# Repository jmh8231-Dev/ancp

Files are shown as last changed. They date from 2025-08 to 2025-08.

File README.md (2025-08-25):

# ANCP Rocket Motor Test Station (Rev 2.0)

> 고정추진제 로켓 모터(ANCP) 지상시험을 위한 **정밀 계측·점화 제어 스테이션**  
> 고정밀 아날로그 체인(로드셀/압력/열전대), **안전 중심 점화 시퀀스**, **2″ LCD(LVGL9 + SPI DMA)** GUI, PC 텔레메트리 지원

보드 히어로 이미지

---

##  주요 기능

- **안전 중심 점화 플로우**
  - 물리 **IGN 스위치** 감지 → 카운트다운 → 온도/추력 인터록 → 핫와이어 제어
  - 모터/보드/PC 준비 상태 점검(미준비 시 시험 중지)
- **정밀 계측 체인**
  - 로드셀(추력), 챔버 압력, 노즐/내부 온도(열전대), IMU 진동
  - 메인/IGN 배터리 **셀 별 전압** + 메인 배터리 전류(INA219)
- **2″ LCD GUI (LVGL v9)**
  - **SPI DMA** 플러시(논블로킹), SquareLine Studio 기반 화면
  - Idle/Test/Config/Cal 페이지, FPS 확보 위해 라인 버퍼 + DMA 이중버퍼
- **EEPROM 기반 설정/보정**
  - **32B 페이지** 체크섬 저장 포맷(캘리브레이션 오프셋/설정값 무결성 보장)
- **PC/RF 텔레메트리**
  - 헤더·길이·페이로드·체크섬으로 구성된 패킷 전송
- **RTOS 태스킹**
  - sensing / gui / comms / control / logging 분리

---

##  하드웨어 개요

| 항목 | 부품 |
|---|---|
| MCU | **STM32H723VGT6** (H7, 12 MHz TCXO) |
| 정밀 ADC | **ADS1262IPW** (ΔΣ, 24-bit) |
| SPI 절연 | **ADuM4151** (MCU–ADC) |
| 기준전압 | **ADR4525D** |
| Op-Amp | **OPA189**, **MCP6022**, **TLV9351** |
| 전류 센서 | **INA219** (메인 배터리) |
| IMU | **BNO085** (I²C) |
| 온도 센서 | **AS6221** (MOSFET 온도) |
| EEPROM | **AT24C08C** (I²C) |
| 전원 | LM2596S-3.3, **CC6-1212DR-E**(±12 V) → **LT3045**(+5 V) / **LT3094**(−5 V) / **TPS79225**(+2.5 V) / **TPS72325**(−2.5 V) |
| 점화 경로 | **TC427** 게이트 드라이버 + **IRF1404** 파워 MOSFET, 물리 **IGN SW** |
| I/O | 2″ LCD, F1–F4 버튼, 부저, USB-UART(FT232RL), RF 모듈, ST-Link, 밸런스 잭 |

**3D 렌더 (Top)**  
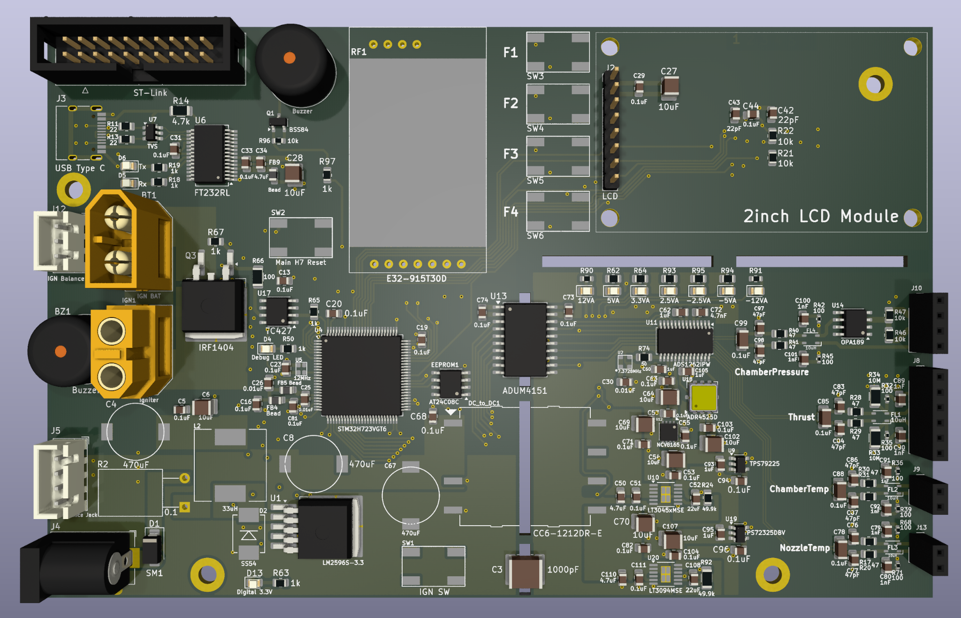
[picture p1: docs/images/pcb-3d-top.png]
PCB 3D Top


**PCB 레이아웃(Top Routed)**  
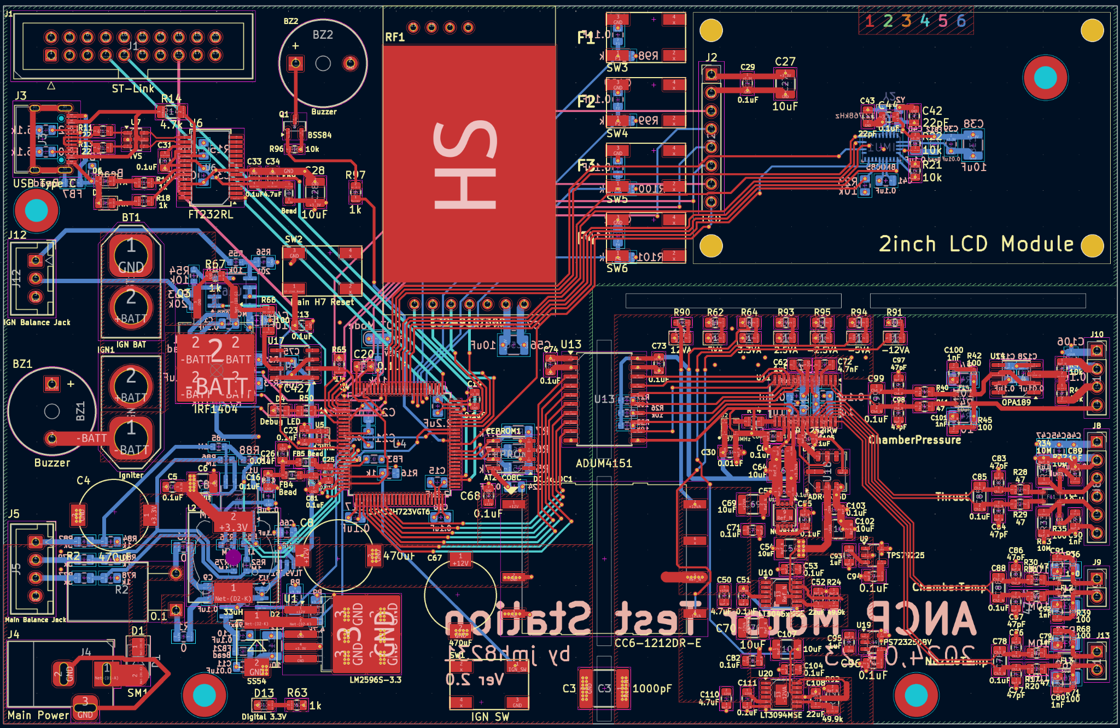
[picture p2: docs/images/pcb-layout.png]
PCB Layout


---

##  펌웨어 개요

- **프레임워크**: STM32Cube HAL (+ FreeRTOS 선택)
- **GUI**: **LVGL v9** / **SquareLine Studio**(UI 설계)
- **LCD 드라이버**: **ST7789 (SPI4 + DMA)**  
  - `fw/Drivers/lcd/LCD_2inch_st7789_v9_dma.c` — ST7789 초기화 + DMA 라인 스트리머  
  - `fw/Drivers/lcd/LVGL9_ST7789_Port_ULP.c` — LVGL9 디스플레이 포트(플러시/세마포어)  
  - `fw/Drivers/board/DEV_Config_h7.c` — SPI4 DMA, D-Cache clean, TIM3 PWM 백라이트, OS-aware delay
- **정밀 ADC(ADS1262)**: SPI(절연) 드라이버, 채널/게인/SPS 매트릭스, 오프셋 CAL
- **EEPROM(AT24C08C)**: 페이지 쓰기/검증, 설정·보정값 저장
- **주요 태스크(권장)**: `task_gui`, `task_sense_fast`, `task_comms`, `task_control`, `task_logging`

### LVGL & LCD 초기화 예시
```c
// main.c
extern void lv_port_disp_init_st7789_v9_ulp(void);

void app_gui_init(void) {
    lv_init();
    lv_port_disp_init_st7789_v9_ulp();  // DMA flush, flush_wait 포함
    // SquareLine 생성 코드 호출 ...
}
```

> **D-Cache ON** 환경에서는 DMA 전 송신 버퍼에 대해 **SCB_CleanDCache_by_Addr()** 처리 필수. 위 파일들에 구현 포함.

---

##  캘리브레이션 & EEPROM 포맷

**ADC Zero-Offset CAL**: *(ch, gain, sps)* 조합별로 오프셋 저장. 부팅 시 전 페이지 스캔 → **이중 체크섬** 검증 → RAM LUT 로드.

```
[32B Page Format]  (1 페이지 = 4개의 Offset)
0-1   : "EP" (헤더)
2     : CH/Gain 상위 3비트(6..3)
3     : SPS
4-7   : OFFSET[ch][gain][sps] (int32/Q-format)
8-13  : 다음 CH/Gain/SPS + OFFSET
14-15 : CHECKSUM #1 (0..13)

16-17 : "EP"
18-19 : CH/Gain/SPS
20-25 : OFFSET
26-29 : 다음 CH/Gain/SPS + OFFSET
30-31 : CHECKSUM #2 (16..29)
```

- **쓰기 시퀀스**: 새 페이지 작성 → 읽기 검증 → 성공 시 구버전 페이지 폐기(저널링)
- **유효성 실패 시**: 기본 오프셋(0)로 부팅 + Cal 페이지 경고 표시

---

## 시험/점화 플로우

1. **Self-check**: 센서 연결/EEPROM 무결성/배터리 상태/PC 준비 여부
2. **IGN SW ON** → **ANCP Test** 모드 자동 진입
3. 로드셀 **Auto-tare** → **카운트다운**(가변)
4. 점화 로직(예시):
```c
if (mosfet_temp < T_th && thrust < F_th)  hotwire_on();
else if (mosfet_temp > T_th && thrust < F_th) { hotwire_off(); show_overheat(); }
else hotwire_off(); // ignition success
```
5. 실시간 데이터 **PC 전송** + 로깅

**전송 패킷(예시)**: `0x48 0x53 | type | len | payload | CRC16`

---

## 스키매틱 스냅샷

**Main Power**  
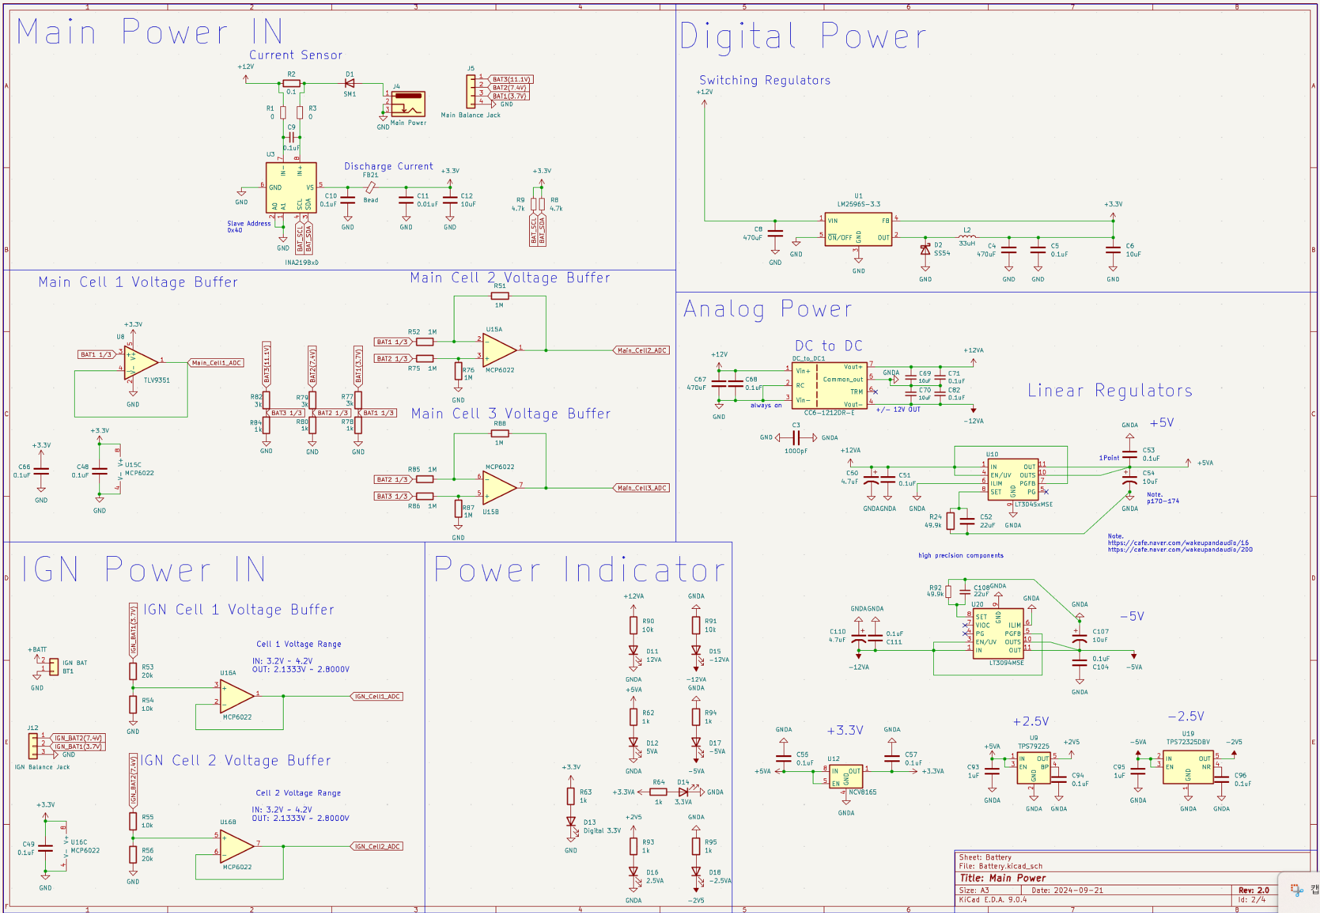
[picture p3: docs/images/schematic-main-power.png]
Main Power


**MCU**  
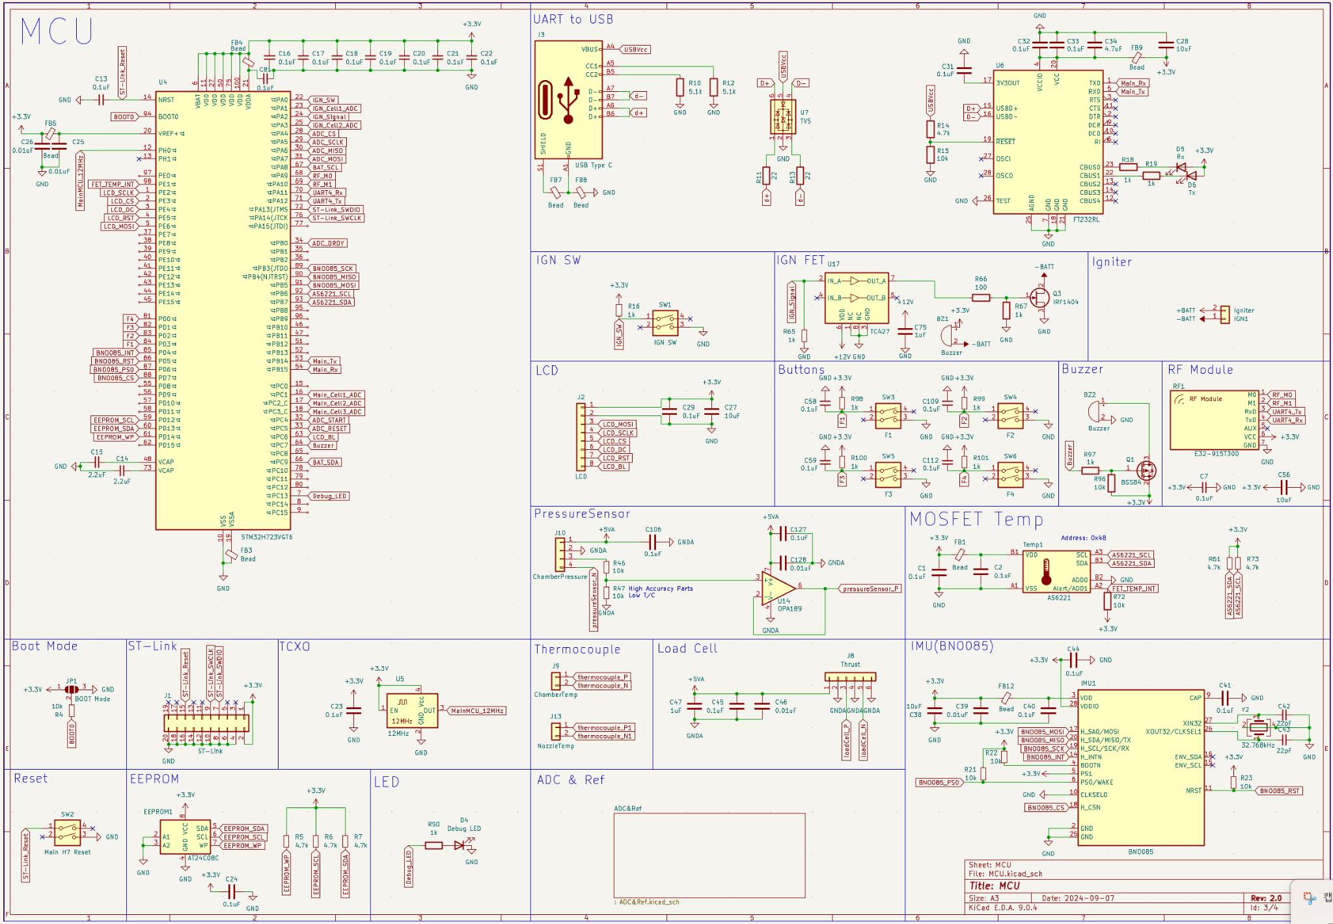
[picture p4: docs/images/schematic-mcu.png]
MCU


**Analog/ADC/Isolation**  
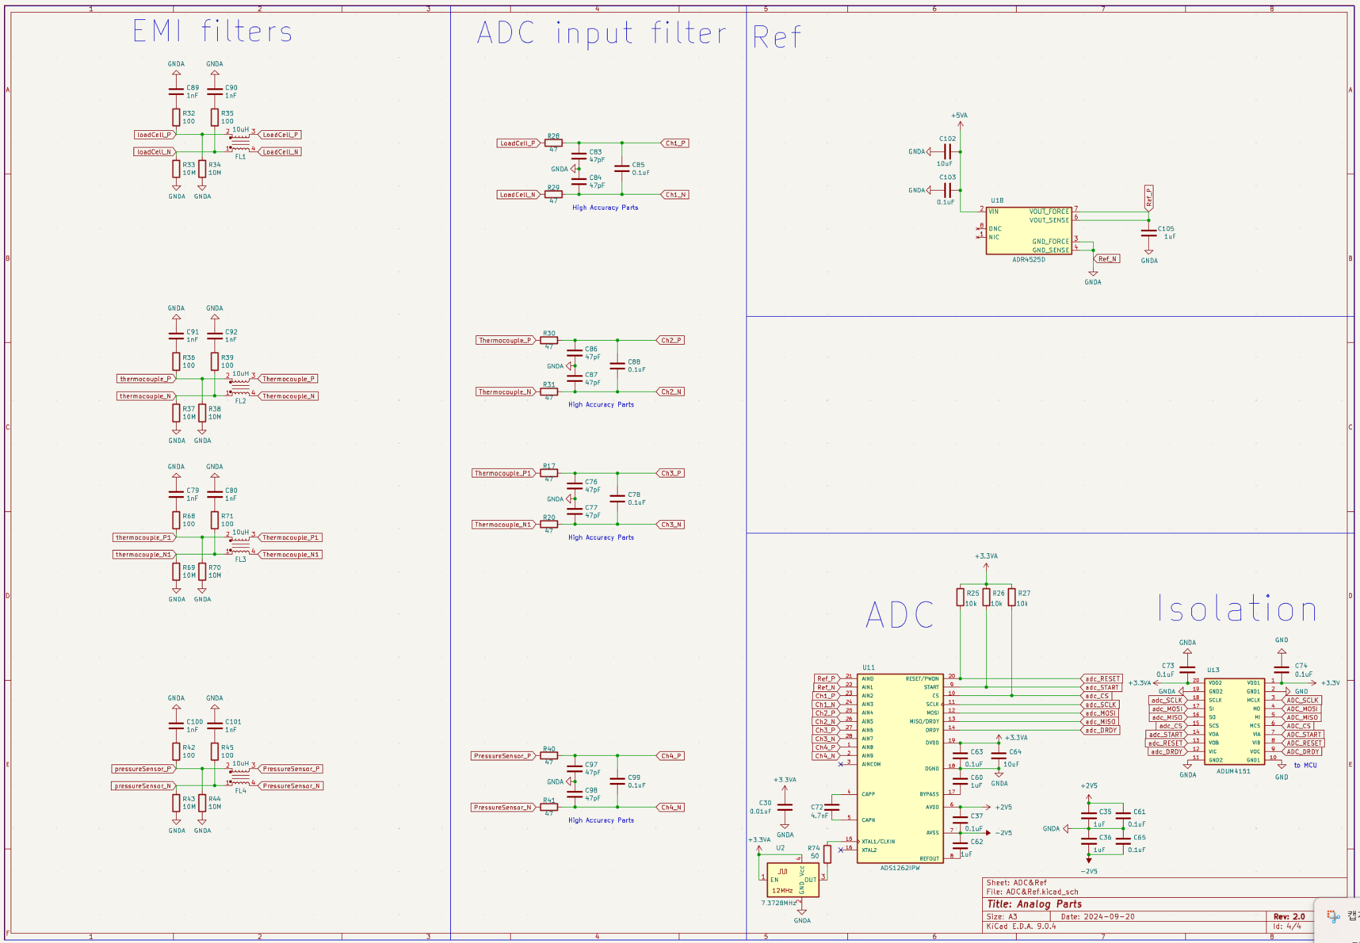
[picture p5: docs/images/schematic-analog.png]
Analog


---

## 빌드 & 플래시

- **툴체인**: STM32CubeIDE(H7), ARM GCC, (선택) FreeRTOS  
- **Cube 설정 핵심**  
  - SPI4 TX DMA(FIFO 사용), CS/DC/RST/BL GPIO  
  - TIM3 PWM → 백라이트  
  - 1 ms 타이머 → `lv_tick_inc()`  
  - D-Cache 사용 시 DMA 버퍼 **clean** 처리  
- **빌드**
  ```bash
  git clone https://github.com/jmh8231-Dev/ancp
  # STM32CubeIDE에서 .ioc 열기 → 빌드 → ST-Link로 플래시
  ```
- **첫 부팅**: Idle 화면 → 센서/배터리 상태 확인

---

## 문서 구조

```
ancp/
├─ fw/
│  ├─ Core/                 # CubeMX 생성 코드
│  ├─ Drivers/
│  │  ├─ lvgl/              # LVGL v9
│  │  ├─ lcd/               # LCD_2inch_st7789_v9_dma.c, LVGL9_ST7789_Port_ULP.c
│  │  └─ board/             # DEV_Config_h7.c 등
│  ├─ app/                  # tasks, ads1262, eeprom, telemetry, state machine
│  └─ middleware/           # FreeRTOS(선택)
├─ hw/                      # 회로/PCB/거버
├─ docs/
│  └─ images/               # 사진/스크린샷
└─ README.md
```

## 주의

- 방폭/방염 환경, 방호벽, 소화 장비, **E-Stop** 필수
- 시험 전 인터록/센서/전원/배선 재점검

---

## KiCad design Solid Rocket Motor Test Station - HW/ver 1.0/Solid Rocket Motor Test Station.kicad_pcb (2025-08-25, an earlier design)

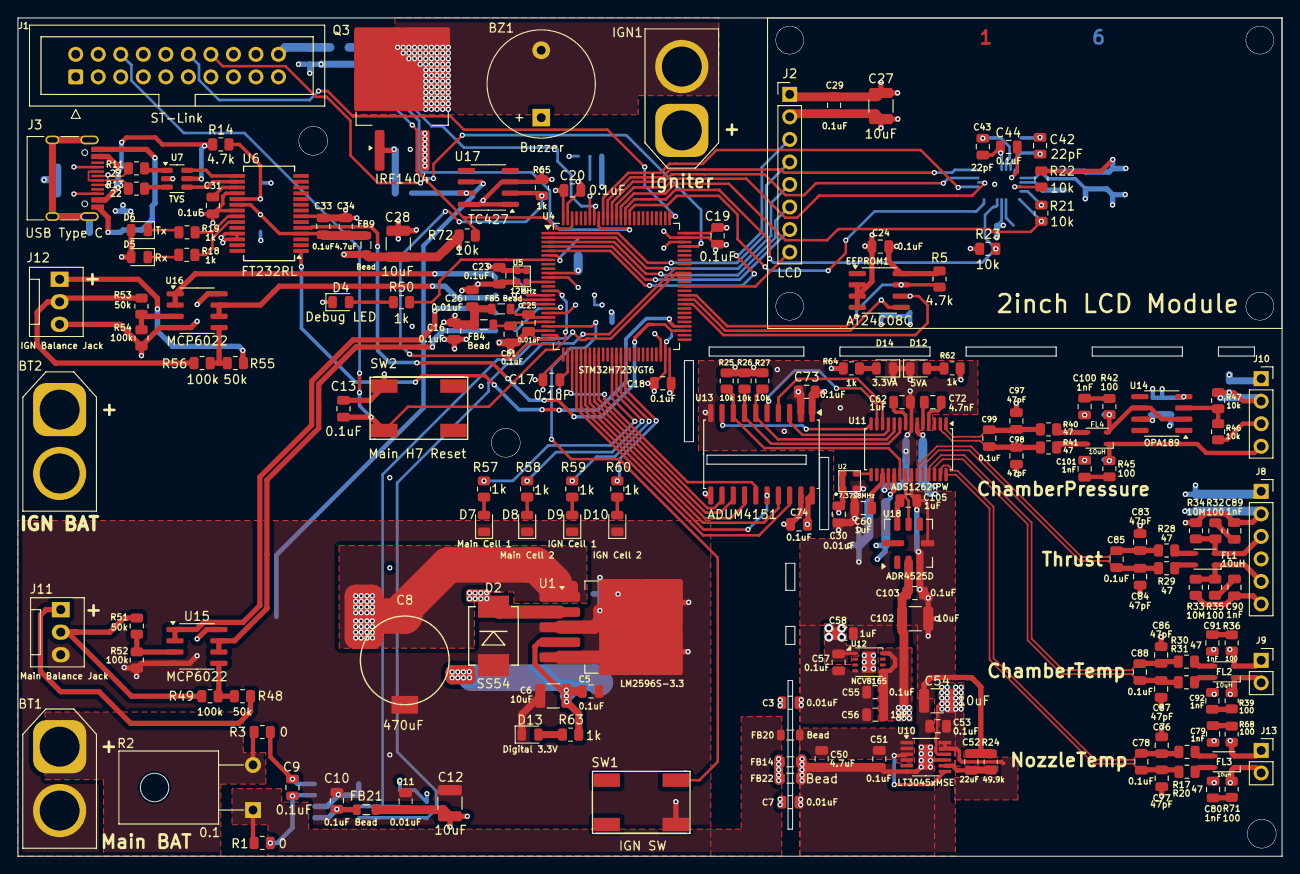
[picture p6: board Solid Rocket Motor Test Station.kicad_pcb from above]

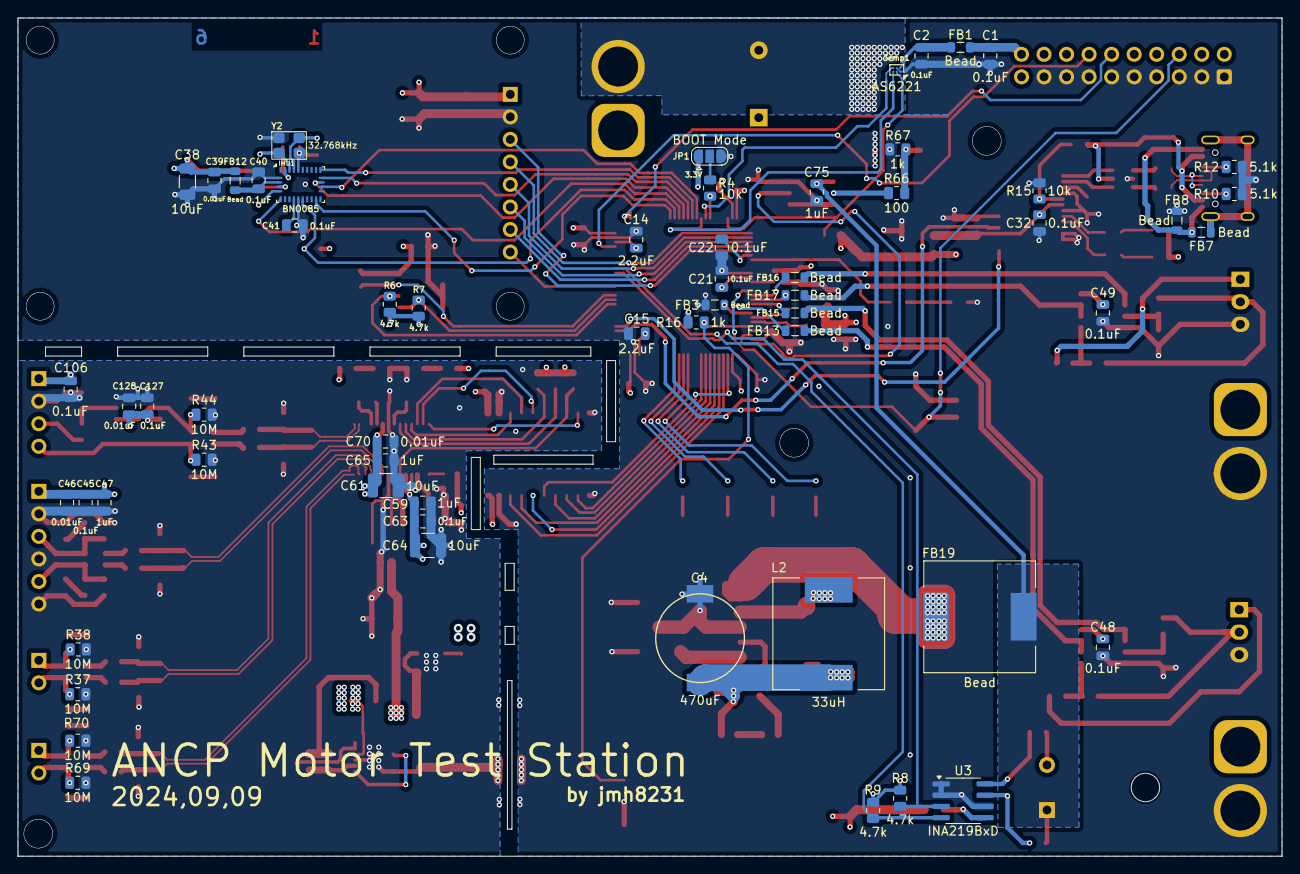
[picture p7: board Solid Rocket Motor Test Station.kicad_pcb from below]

Board: 6 copper layers, 142.5 x 94.5 mm, 235 parts (60 on the bottom side), 161 nets.

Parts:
BT1: Main BAT; AMASS_XT60-F_1x02_P7.20mm_Vertical
BT2: IGN BAT; AMASS_XT60-F_1x02_P7.20mm_Vertical
BZ1: Buzzer; Buzzer_12x9.5RM7.6
C1, C2, C5, C9, C10, C13, C16, C17, C18, C19, C20, C21, C22, C23, C24, C29, C31, C32, C33, C40, C41, C44, C45, C48, C49, C51, C53, C55, C57, C63, C73, C74, C78, C81, C85, C88, C99, C103, C106, C127: 0.1uF; C_0805_2012Metric
C3, C7, C11, C25, C26, C30, C39, C46, C70, C128: 0.01uF; C_0805_2012Metric
C4, C8: 470uF; MVG25WV470M
C6, C12, C27, C28, C54, C61, C64, C102: 10uF; C_1210_3225Metric
C14, C15: 2.2uF; C_0805_2012Metric
C34, C50: 4.7uF; C_0805_2012Metric
C38: 10uF; C_1206_3216Metric
C42, C43: 22pF; C_0805_2012Metric
C47, C56, C58, C59, C60, C62, C65, C75, C105: 1uF; C_0805_2012Metric
C52: 22uF; C_0805_2012Metric
C72: 4.7nF; C_0805_2012Metric
C76, C77, C83, C84, C86, C87, C97, C98: 47pF; C_0805_2012Metric
C79, C80, C89, C90, C91, C92, C100, C101: 1nF; C_0805_2012Metric
D2: SS54
D4: Debug LED; LED_0805_2012Metric
D5: Rx; LED_0805_2012Metric
D6: Tx; LED_0805_2012Metric
D7: Main Cell 1; LED_0805_2012Metric
D8: Main Cell 2; LED_0805_2012Metric
D9: IGN Cell 1; LED_0805_2012Metric
D10: IGN Cell 2; LED_0805_2012Metric
D12: 5VA; LED_0805_2012Metric
D13: Digital 3.3V; LED_0805_2012Metric
D14: 3.3VA; LED_0805_2012Metric
EEPROM1: AT24C08C; SOIC-8_3.9x4.9mm_P1.27mm
FB1, FB3, FB4, FB5, FB7, FB8, FB9, FB12, FB13, FB14, FB15, FB16, FB17, FB20, FB21, FB22: Bead; L_0805_2012Metric
FB19: Bead; L_12x12mm_H8mm
FL1, FL2, FL3, FL4: 10uH; L_CommonModeChoke_TDK_ACM2520-2P
IGN1: Igniter; AMASS_XT60-M_1x02_P7.20mm_Vertical
IMU1: BNO085; LGA-28_5.2x3.8mm_P0.5mm
J1: ST-Link; IDC-Header_2x10_P2.54mm_Vertical
J2: LCD; PinHeader_1x08_P2.54mm_Vertical
J3: USB Type C; USB_C_Receptacle_HRO_TYPE-C-31-M-12
J8: Thrust; PinSocket_1x06_P2.54mm_Vertical
J9: ChamberTemp; PinSocket_1x02_P2.54mm_Vertical
J10: ChamberPressure; PinSocket_1x04_P2.54mm_Vertical
J11: Main Balance Jack; FanPinHeader_1x03_P2.54mm_Vertical
J12: IGN Balance Jack; FanPinHeader_1x03_P2.54mm_Vertical
J13: NozzleTemp; PinSocket_1x02_P2.54mm_Vertical
JP1: BOOT Mode; SolderJumper-3_P1.3mm_Open_RoundedPad1.0x1.5mm
L2: 33uH; L_12x12mm_H8mm
Q3: IRF1404; TO-263-2
R1, R3: 0; R_0805_2012Metric
R2: 0.1; TO-126-2_Horizontal_TabDown
R4, R15, R21, R22, R23, R25, R26, R27, R46, R47, R72: 10k; R_0805_2012Metric
R5, R6, R7, R8, R9, R14: 4.7k; R_0805_2012Metric
R10, R12: 5.1k; R_0805_2012Metric
R11, R13: 22; R_0805_2012Metric
R16, R18, R19, R50, R57, R58, R59, R60, R62, R63, R64, R65, R67: 1k; R_0805_2012Metric
R17, R20, R28, R29, R30, R31, R40, R41: 47; R_0805_2012Metric
R24: 49.9k; R_0805_2012Metric
R32, R35, R36, R39, R42, R45, R66, R68, R71: 100; R_0805_2012Metric
R33, R34, R37, R38, R43, R44, R69, R70: 10M; R_0805_2012Metric
R48, R51, R53, R55: 50k; R_0805_2012Metric
R49, R52, R54, R56: 100k; R_0805_2012Metric
SW1: IGN SW; SW_SMD_IT-1107
SW2: Main H7 Reset; SW_SMD_IT-1107
Temp1: AS6221; WLCSP-6_1.4x1.0mm_P0.4mm
U1: LM2596S-3.3; TO-263-5_TabPin3
U2: 7.3728MHz; ASDMB-OSC
U3: INA219BxD; SOIC-8_3.9x4.9mm_P1.27mm
U4: STM32H723VGT6; LQFP-100_14x14mm_P0.5mm
U5: 12MHz; ECS-TXO-2016
U6: FT232RL; SSOP-28_5.3x10.2mm_P0.65mm
U7: TVS; SOT-23-6
U10: LT3045xMSE; MSOP-12-1EP_3x4mm_P0.65mm_EP1.65x2.85mm
U11: ADS1262IPW; TSSOP-28_4.4x9.7mm_P0.65mm
U12: NCV8165; DFN-8-1EP_3x3mm_P0.65mm_EP1.55x2.4mm
U13: ADUM4151; SOIC-20W_7.5x12.8mm_P1.27mm
U14: OPA189; SOIC-8_3.9x4.9mm_P1.27mm
U15, U16: MCP6022; SOIC-8_3.9x4.9mm_P1.27mm
U17: TC427; SOIC-8_3.9x4.9mm_P1.27mm
U18: ADR4525D; Analog_LCC-8_5x5mm_P1.27mm
Y2: 32.768kHz; XC32M4

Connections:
+3.3V: BZ1.1 (-), C1.2, C4.1, C5.1, C6.1, C11.1, C12.1, C16.1, C17.1, C18.1, C19.1, C20.1, C21.1, C22.1, C23.1, C24.1, C26.2, C27.1, C28.1, C29.1, C38.1, C39.2, C44.1, C48.2, C49.2, C74.2, D5.2 (A), D6.2 (A), EEPROM1.8 (VCC), FB1.1, FB4.2, FB5.1, FB9.2, FB12.1, FB21.2, IMU1.5 (PS1), IMU1.28 (VDDIO), J1.19, J1.20, J2.1, JP1.1 (A), L2.2, R5.1, R6.1, R7.1, R8.1, R9.1, R16.1, R21.2, R22.2, R23.2, R63.1, R72.1, U1.4 (FB), U4.6 (VBAT), U4.11 (VDD), U4.27 (VDD), U4.50 (VDD), U4.75 (VDD), U4.100 (VDD), U5.1 (EN), U5.4 (Vcc), U13.20 (VDD2), U15.8 (V+), U16.8 (V+)
+3.3VA: C30.1, C57.2, C58.1, C59.1, C63.1, C64.1, C73.2, R25.1, R26.1, R27.1, R64.1, U2.1 (EN), U2.4 (Vcc), U11.19 (DVDD), U12.1 (OUT), U13.1 (VDD1)
+5VA: C45.1, C46.1, C47.1, C53.2, C54.1, C55.2, C56.1, C61.1, C65.1, C70.1, C102.1, C103.1, C106.1, C127.2, C128.2, J8.1, J10.1, R62.1, U10.10 (OUTS), U10.11 (OUT), U10.12 (OUT), U11.6 (AVDD), U12.5 (EN), U12.8 (IN), U14.7 (V+), U18.2 (VIN)
+8V: C75.2, FB19.1, FB20.1, R1.2, R2.1, U17.6 (VDD)
+BATT: BT2.1 (+), IGN1.1
-BATT: BZ1.2 (+), IGN1.2, Q3.2 (D)
ADC_CS: U4.28 (PA4), U13.15 (SCS)
ADC_DRDY: U4.34 (PB0), U13.12 (VIC)
ADC_MISO: U4.30 (PA6), U13.16 (SO)
ADC_MOSI: U4.31 (PA7), U13.17 (SI)
ADC_RESET: U4.33 (PC5), U13.13 (VOB)
ADC_SCLK: U4.29 (PA5), U13.18 (SCLK)
ADC_START: U4.32 (PC4), U13.14 (VOA)
AS6221_SCL: Temp1.A3 (SCL), U4.92 (PB6)
AS6221_SDA: Temp1.B3 (SDA), U4.93 (PB7)
BAT1(3.7V): J11.2, R49.2, R51.1
BAT2(7.4V): J11.1, R48.1
BAT_SCL: R9.2, U3.4 (SCL), U4.67 (PA8)
BAT_SDA: R8.2, U3.3 (SDA), U4.66 (PC9)
BNO085_CS: IMU1.18 (H_CSN), U4.88 (PD7)
BNO085_INT: IMU1.14 (H_INTN), U4.85 (PD4)
BNO085_MISO: IMU1.20 (H_SDA/MISO/TX), U4.90 (PB4(NJTRST))
BNO085_MOSI: IMU1.17 (H_SA0/MOSI), U4.91 (PB5)
BNO085_PS0: IMU1.6 (PS0/WAKE), R21.1, U4.87 (PD6)
BNO085_RST: IMU1.11 (NRST), R23.1, U4.86 (PD5)
BNO085_SCK: IMU1.19 (H_SCL/SCK/RX), U4.89 (PB3(JTDO)
BOOT0: R4.2, U4.94 (BOOT0)
Ch1_N: C84.2, C85.2, R29.1, U11.24 (AIN3)
Ch1_P: C83.1, C85.1, R28.1, U11.23 (AIN2)
Ch2_N: C87.2, C88.2, R31.1, U11.26 (AIN5)
Ch2_P: C86.1, C88.1, R30.1, U11.25 (AIN4)
Ch3_N: C77.2, C78.2, R20.1, U11.28 (AIN7)
Ch3_P: C76.1, C78.1, R17.1, U11.27 (AIN6)
Ch4_N: C98.2, C99.2, R41.1, U11.2 (AIN9)
Ch4_P: C97.1, C99.1, R40.1, U11.1 (AIN8)
D+: U6.15 (USBD+), U7.6
D-: U6.16 (USBD-), U7.4
Debug_LED: R50.1, U4.7 (PC13)
EEPROM_SCL: EEPROM1.6 (SCL), R6.2, U4.59 (PD12)
EEPROM_SDA: EEPROM1.5 (SDA), R7.2, U4.60 (PD13)
EEPROM_WP: EEPROM1.7 (WP), R5.2, U4.61 (PD14)
FET_TEMP_INT: R72.2, Temp1.A2 (Alert/ADD1), U4.98 (PE1)
GND: BT1.2 (-), BT2.2 (-), C1.1, C2.2, C3.2, C4.2, C5.2, C6.2, C7.2, C8.2, C10.2, C11.2, C12.2, C13.1, C14.1, C15.1, C16.2, C17.2, C18.2, C19.2, C20.2, C21.2, C22.2, C23.2, C24.2, C25.1, C26.1, C27.2, C28.2, C29.2, C31.2, C32.2, C33.2, C34.2, C38.2, C39.1, C40.2, C41.1, C42.2, C43.2, C44.2, C48.1, C49.1, C74.1, C75.1, C81.2, D2.2 (A), D4.1 (K), D7.1 (K), D8.1 (K), D9.1 (K), D10.1 (K), D13.1 (K), EEPROM1.2 (A1), EEPROM1.3 (A2), EEPROM1.4 (GND), FB3.2, FB8.2, FB14.1, FB22.1, IMU1.2 (GND), IMU1.10 (CLKSEL0), IMU1.25 (GND), J1.1, J1.3, J1.5, J1.7, J1.9, J1.11, J1.13, J1.15, J1.17, J2.2, J11.3, J12.3, JP1.3 (B), Q3.3 (S), R10.2, R12.2, R15.2, R52.2, R54.2, R65.1, R67.2, SW1.3, SW2.3, Temp1.A1 (VSS), Temp1.B2 (ADD0), U1.3 (GND), U1.5 (~ON/OFF), U3.1 (A1), U3.2 (A0), U3.6 (GND), U4.10 (VSS), U4.23 (PA1), U4.25 (PA3), U4.26 (VSS), U4.49 (VSS), U4.74 (VSS), U4.99 (VSS), U5.2 (GND), U6.7 (GND), U6.18 (GND), U6.21 (GND), U6.25 (AGND), U6.26 (TEST), U7.2, U13.11 (GND2), U13.19 (GND2), U15.4 (V-), U16.4 (V-), U17.1 (NC), U17.3 (GND), U17.8 (NC), Y2.2, Y2.4
IGN_BAT1(3.7V): J12.2, R53.1, R56.2
IGN_BAT2(7.4V): J12.1, R55.1
IGN_Cell1_ADC: FB16.2, U4.15 (PC0)
IGN_Cell2_ADC: FB17.2, U4.16 (PC1)
IGN_SW: R16.2, SW1.1, U4.22 (PA0)
IGN_Signal: R65.2, U4.24 (PA2), U17.2 (IN_A)
I_Power_Cell1: R59.1, U4.39 (PE9)
I_Power_Cell2: R60.1, U4.40 (PE10)
LCD_BL: J2.8, U4.63 (PC6)
LCD_CS: J2.5, U4.2 (PE3)
LCD_DC: J2.6, U4.3 (PE4)
LCD_MOSI: J2.3, U4.5 (PE6)
LCD_RST: J2.7, U4.4 (PE5)
LCD_SCLK: J2.4, U4.1 (PE2)
LoadCell_N: FL1.4, R29.2
LoadCell_P: FL1.3, R28.2
M_Power_Cell1: R57.1, U4.37 (PE7)
M_Power_Cell2: R58.1, U4.38 (PE8)
MainMCU_12MHz: U4.12 (PH0), U5.3 (OUT)
Main_Cell1_ADC: FB15.2, U4.17 (PC2_C)
Main_Cell2_ADC: FB13.2, U4.18 (PC3_C)
Main_Rx: U4.54 (PB15), U6.1 (TXD)
Main_Tx: U4.53 (PB14), U6.5 (RXD)
unnamed: BT1.1 (+), R2.2, R3.1
unnamed: C14.2, U4.73 (VCAP)
unnamed: C15.2, U4.48 (VCAP)
unnamed: C79.2, R68.1
unnamed: C80.2, R71.1
unnamed: C89.2, R32.1
unnamed: C90.2, R35.1
unnamed: C91.2, R36.1
unnamed: C92.2, R39.1
unnamed: C100.2, R42.1
unnamed: C101.2, R45.1
unnamed: D2.1 (K), L2.1, U1.2 (OUT)
unnamed: D4.2 (A), R50.2
unnamed: D5.1 (K), R18.2
unnamed: D6.1 (K), R19.2
unnamed: D7.2 (A), R57.2
unnamed: D8.2 (A), R58.2
unnamed: D9.2 (A), R59.2
unnamed: D10.2 (A), R60.2
unnamed: D12.2 (A), R62.2
unnamed: D13.2 (A), R63.2
unnamed: D14.2 (A), R64.2
unnamed: FB7.2, FB8.1, J3.A1 (GND), J3.A12 (GND), J3.B1 (GND), J3.B12 (GND)
unnamed: IMU1.4 (BOOTN), R22.1
unnamed: C41.2, IMU1.9 (CAP)
unnamed: C40.1, FB12.2, IMU1.3 (VDD)
unnamed: C42.1, IMU1.27 (XIN32), Y2.3
unnamed: C43.1, IMU1.26 (XOUT32/CLKSEL1), Y2.1
unnamed: J3.A5 (CC1), R12.1
unnamed: J3.B5 (CC2), R10.1
unnamed: FB7.1, J3.S1 (SHIELD)
unnamed: J10.3, R46.2
unnamed: JP1.2 (C), R4.1
unnamed: Q3.1 (G), R66.2, R67.1
unnamed: R11.2, U7.1
unnamed: R13.2, U7.3
unnamed: C2.1, FB1.2, Temp1.B1 (VDD)
unnamed: C8.1, FB19.2, U1.1 (VIN)
unnamed: C9.2, R3.2, U3.8 (IN+)
unnamed: C9.1, R1.1, U3.7 (IN-)
unnamed: C10.1, FB21.1, U3.5 (VS)
unnamed: C81.1, FB4.1, U4.21 (VDDA)
unnamed: C25.2, FB5.2, U4.20 (VREF+)
unnamed: FB3.1, U4.19 (VSSA)
unnamed: C31.1, U6.17 (3V3OUT)
unnamed: R18.1, U6.23 (CBUS0)
unnamed: R19.1, U6.22 (CBUS1)
unnamed: C32.1, C33.1, C34.1, FB9.1, U6.4 (VCCIO), U6.20 (VCC)
unnamed: R14.2, R15.1, U6.19 (~RESET)
unnamed: C50.1, C51.1, FB20.2, U10.1 (IN), U10.2 (IN), U10.3 (IN), U10.4 (EN/UV), U10.7 (PGFB)
unnamed: C52.1, R24.2, U10.8 (SET)
unnamed: C60.2, U11.17 (BYPASS)
unnamed: C72.2, U11.5 (CAPN)
unnamed: C72.1, U11.4 (CAPP)
unnamed: C62.2, U11.8 (REFOUT)
unnamed: U2.3 (OUT), U11.15 (XTAL1/CLKIN)
unnamed: R46.1, R47.2, U14.3 (+)
unnamed: R51.2, R52.1, U15.3 (+)
unnamed: FB15.1, U15.1, U15.2 (-)
unnamed: R48.2, R49.1, U15.5 (+)
unnamed: FB13.1, U15.6 (-), U15.7
unnamed: R53.2, R54.1, U16.3 (+)
unnamed: FB16.1, U16.1, U16.2 (-)
unnamed: R55.2, R56.1, U16.5 (+)
unnamed: FB17.1, U16.6 (-), U16.7
unnamed: R66.1, U17.7 (OUT_A)
PressureSensor_N: FL4.4, R41.2
PressureSensor_P: FL4.3, R40.2
Ref_N: C3.1, C7.1, C30.2, C45.2, C46.2, C47.2, C50.2, C51.2, C52.2, C53.1, C54.2, C55.1, C56.2, C57.1, C58.2, C59.2, C60.1, C61.2, C62.1, C63.2, C64.2, C65.2, C70.2, C73.1, C76.2, C77.1, C79.1, C80.1, C83.2, C84.1, C86.2, C87.1, C89.1, C90.1, C91.1, C92.1, C97.2, C98.1, C100.1, C101.1, C102.2, C103.2, C105.1, C106.2, C127.1, C128.1, D12.1 (K), D14.1 (K), FB14.2, FB22.2, J8.2, J8.4, J8.6, J10.2, R24.1, R33.2, R34.2, R37.2, R38.2, R43.2, R44.2, R47.1, R69.2, R70.2, U2.2 (GND), U10.6 (ILIM), U10.9 (GND), U10.13 (GND), U11.7 (AVSS), U11.18 (DGND), U11.22 (AIN1), U12.4 (GND), U12.9 (EXP), U13.2 (GND1), U13.10 (GND1), U14.4 (V-), U18.3 (GND_FORCE), U18.4 (GND_SENSE)
Ref_P: C105.2, U11.21 (AINO), U18.6 (VOUT_SENSE), U18.7 (VOUT_FORCE)
ST-Link_Reset: C13.2, J1.6, SW2.1, U4.14 (NRST)
ST-Link_SWCLK: J1.12, U4.76 (PA14(JTCK)
ST-Link_SWDIO: J1.14, U4.72 (PA13(JTMS)
Thermocouple_N: FL2.4, R31.2
Thermocouple_N1: FL3.4, R20.2
Thermocouple_P: FL2.3, R30.2
Thermocouple_P1: FL3.3, R17.2
USBVcc: J3.A4 (VBUS), J3.A9 (VBUS), J3.B4 (VBUS), J3.B9 (VBUS), R14.1, U7.5
adc_CS: R27.2, U11.10 (CS), U13.6 (MCS)
adc_DRDY: U11.14 (DRDY), U13.9 (VOC)
adc_MISO: U11.13 (MISO/DRDY), U13.5 (MI)
adc_MOSI: U11.12 (MOSI), U13.4 (MO)
adc_RESET: R25.2, U11.20 (RESET/PWDN), U13.8 (VIB)
adc_SCLK: U11.11 (SCLK), U13.3 (MCLK)
adc_START: R26.2, U11.9 (START), U13.7 (VIA)
d+: J3.A6 (D+), J3.B6 (D+), R11.1
d-: J3.A7 (D-), J3.B7 (D-), R13.1
loadCell_N: FL1.1, J8.5, R33.1, R35.2
loadCell_P: FL1.2, J8.3, R32.2, R34.1
pressureSensor_N: FL4.1, J10.4, R43.1, R45.2
pressureSensor_P: FL4.2, R42.2, R44.1, U14.2 (-), U14.6
thermocouple_N: FL2.1, J9.2, R37.1, R39.2
thermocouple_N1: FL3.1, J13.2, R69.1, R71.2
thermocouple_P: FL2.2, J9.1, R36.2, R38.1
thermocouple_P1: FL3.2, J13.1, R68.2, R70.1

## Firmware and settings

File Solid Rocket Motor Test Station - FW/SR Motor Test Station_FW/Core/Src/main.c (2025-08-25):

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
/* Includes ------------------------------------------------------------------*/
#include "main.h"
#include "adc.h"
#include "dma.h"
#include "i2c.h"
#include "spi.h"
#include "tim.h"
#include "usart.h"
#include "gpio.h"

/* USER CODE BEGIN Includes */
#include "stdio.h"
#include "../../lvgl/lvgl.h"
#include "../../lvgl/demos/benchmark/lv_demo_benchmark.h"
#include "LCD_2inch_st7789_v9_dma.h"
#include "DEV_Config_h7.h"
#include "LVGL9_ST7789_Port_ULP.h"

/* USER CODE END Includes */

/* USER CODE BEGIN PM */
int _write(int file, char* p, int len){
	HAL_UART_Transmit(&huart1, p, len, 10);
	return len;
}

/* USER CODE END PM */


void SystemClock_Config(void);
void PeriphCommonClock_Config(void);
static void MPU_Config(void);
static void MX_NVIC_Init(void);
/**
  * @brief  The application entry point.
  * @retval int
  */
int main(void)
{

  /* MPU Configuration--------------------------------------------------------*/
  MPU_Config();

  /* Enable the CPU Cache */

  /* Enable I-Cache---------------------------------------------------------*/
  SCB_EnableICache();

  /* Enable D-Cache---------------------------------------------------------*/
  SCB_EnableDCache();

  /* MCU Configuration--------------------------------------------------------*/

  /* Reset of all peripherals, Initializes the Flash interface and the Systick. */
  HAL_Init();

  /* Configure the system clock */
  SystemClock_Config();

  /* Configure the peripherals common clocks */
  PeriphCommonClock_Config();

  /* Initialize all configured peripherals */
  MX_GPIO_Init();
  MX_DMA_Init();
  MX_ADC1_Init();
  MX_ADC3_Init();
  MX_I2C1_Init();
  MX_I2C3_Init();
  MX_I2C4_Init();
  MX_SPI1_Init();
  MX_SPI3_Init();
  MX_SPI4_Init();
  MX_TIM3_Init();
  MX_USART1_UART_Init();
  MX_UART4_Init();

  /* Initialize interrupts */
  MX_NVIC_Init();
  /* USER CODE BEGIN 2 */
  lv_init();
  lv_port_disp_init_st7789_v9_ulp();


  /* USER CODE END 2 */

  /* Infinite loop */
  /* USER CODE BEGIN WHILE */
  while (1)
  {
	  lv_timer_handler(); // LVGL 내부 이벤트 처리
	  HAL_Delay(5);       // 주기적 호출
    /* USER CODE END WHILE */

    /* USER CODE BEGIN 3 */
  }
  /* USER CODE END 3 */
}

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
 /* MPU Configuration */

void MPU_Config(void)
{
  MPU_Region_InitTypeDef MPU_InitStruct = {0};

  /* Disables the MPU */
  HAL_MPU_Disable();

  /** Initializes and configures the Region and the memory to be protected
  */
  MPU_InitStruct.Enable = MPU_REGION_ENABLE;
  MPU_InitStruct.Number = MPU_REGION_NUMBER0;
  MPU_InitStruct.BaseAddress = 0x0;
  MPU_InitStruct.Size = MPU_REGION_SIZE_4GB;
  MPU_InitStruct.SubRegionDisable = 0x87;
  MPU_InitStruct.TypeExtField = MPU_TEX_LEVEL0;
  MPU_InitStruct.AccessPermission = MPU_REGION_NO_ACCESS;
  MPU_InitStruct.DisableExec = MPU_INSTRUCTION_ACCESS_DISABLE;
  MPU_InitStruct.IsShareable = MPU_ACCESS_SHAREABLE;
  MPU_InitStruct.IsCacheable = MPU_ACCESS_NOT_CACHEABLE;
  MPU_InitStruct.IsBufferable = MPU_ACCESS_NOT_BUFFERABLE;

  HAL_MPU_ConfigRegion(&MPU_InitStruct);
  /* Enables the MPU */
  HAL_MPU_Enable(MPU_PRIVILEGED_DEFAULT);

}

/**
  * @brief  This function is executed in case of error occurrence.
  * @retval None
  */
void Error_Handler(void)
{
  /* USER CODE BEGIN Error_Handler_Debug */
  /* User can add his own implementation to report the HAL error return state */
  __disable_irq();
  while (1)
  {
  }
  /* USER CODE END Error_Handler_Debug */
}
#ifdef USE_FULL_ASSERT
/**
  * @brief  Reports the name of the source file and the source line number
  *         where the assert_param error has occurred.
  * @param  file: pointer to the source file name
  * @param  line: assert_param error line source number
  * @retval None
  */
void assert_failed(uint8_t *file, uint32_t line)
{
  /* USER CODE BEGIN 6 */
  /* User can add his own implementation to report the file name and line number,
     ex: printf("Wrong parameters value: file %s on line %d\r\n", file, line) */
  /* USER CODE END 6 */
}
#endif /* USE_FULL_ASSERT */

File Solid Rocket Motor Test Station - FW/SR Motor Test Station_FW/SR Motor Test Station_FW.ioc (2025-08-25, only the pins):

Mcu.UserName=STM32H723VGTx
PA0.GPIO_Label=IGN_Button
PA0.Signal=GPXTI0
PA1.GPIO_Label=IGN_Cell1_ADC
PA1.Signal=ADC1_INP17
PA10.GPIO_Label=RF_M1
PA10.Signal=GPIO_Output
PA11.GPIO_Label=RF_Tx
PA11.Signal=UART4_RX
PA12.GPIO_Label=RF_Rx
PA12.Signal=UART4_TX
PA13(JTMS/SWDIO).Signal=DEBUG_JTMS-SWDIO
PA14(JTCK/SWCLK).Signal=DEBUG_JTCK-SWCLK
PA2.GPIO_Label=IGN_Signal
PA2.Signal=GPIO_Output
PA3.GPIO_Label=IGN_Cell2_ADC
PA3.Signal=ADCx_INP15
PA4.GPIO_Label=ADS1262_CS
PA4.Signal=GPIO_Output
PA5.GPIO_Label=ADS1262_SCK
PA5.Signal=SPI1_SCK
PA6.GPIO_Label=ADS1262_MISO
PA6.Signal=SPI1_MISO
PA7.GPIO_Label=ADS1262_MOSI
PA7.Signal=SPI1_MOSI
PA8.GPIO_Label=INA219_SCL
PA8.Signal=I2C3_SCL
PA9.GPIO_Label=RF_M0
PA9.Signal=GPIO_Output
PB0.GPIO_Label=ADS1262_DRDY
PB0.Signal=GPIO_Input
PB14.GPIO_Label=Debug_Tx
PB14.Signal=USART1_TX
PB15.GPIO_Label=Debug_Rx
PB15.Signal=USART1_RX
PB3(JTDO/TRACESWO).GPIO_Label=BNO085_SCK
PB3(JTDO/TRACESWO).Signal=SPI3_SCK
PB4(NJTRST).GPIO_Label=BNO085_MISO
PB4(NJTRST).Signal=SPI3_MISO
PB5.GPIO_Label=BNO085_MOSI
PB5.Signal=SPI3_MOSI
PB6.GPIO_Label=AS6221_SCL
PB6.Signal=I2C1_SCL
PB7.GPIO_Label=AS6221_SDA
PB7.Signal=I2C1_SDA
PC1.GPIO_Label=Main_Cell1_ADC
PC1.Signal=ADCx_INP11
PC13.GPIO_Label=LD1
PC13.Signal=GPIO_Output
PC2_C.GPIO_Label=Main_Cell2_ADC
PC2_C.Signal=ADC3_INP0
PC3_C.GPIO_Label=Main_Cell3_ADC
PC3_C.Signal=ADC3_INP1
PC4.GPIO_Label=ADS1262_START
PC4.Signal=GPIO_Output
PC5.GPIO_Label=ADS1262_RST
PC5.Signal=GPIO_Output
PC6.GPIO_Label=LCD_BL
PC6.Signal=S_TIM3_CH1
PC7.GPIO_Label=Buzzer
PC7.Signal=S_TIM3_CH2
PC9.GPIO_Label=INA219_SDA
PC9.Signal=I2C3_SDA
PD0.GPIO_Label=F4_Button
PD0.Signal=GPIO_Input
PD1.GPIO_Label=F3_Button
PD1.Signal=GPIO_Input
PD12.GPIO_Label=EEPROM_SCL
PD12.Signal=I2C4_SCL
PD13.GPIO_Label=EEPROM_SDA
PD13.Signal=I2C4_SDA
PD14.GPIO_Label=EEPROM_WP
PD14.Signal=GPIO_Output
PD2.GPIO_Label=F2_Button
PD2.Signal=GPIO_Input
PD3.GPIO_Label=F1_Button
PD3.Signal=GPIO_Input
PD4.GPIO_Label=BNO085_INT
PD4.Signal=GPIO_Input
PD5.GPIO_Label=BNO085_RST
PD5.Signal=GPIO_Output
PD6.GPIO_Label=BNO085_PS0
PD6.Signal=GPXTI6
PD7.GPIO_Label=BNO085_CS
PD7.Signal=GPIO_Output
PE2.GPIO_Label=LCD_SCK
PE2.Signal=SPI4_SCK
PE3.GPIO_Label=LCD_CS
PE3.Signal=GPIO_Output
PE4.GPIO_Label=LCD_DC
PE4.Signal=GPIO_Output
PE5.GPIO_Label=LCD_RST
PE5.Signal=GPIO_Output
PE6.GPIO_Label=LCD_MOSI
PE6.Signal=SPI4_MOSI
PH0-OSC_IN.Signal=RCC_OSC_IN
PH1-OSC_OUT.Signal=RCC_OSC_OUT

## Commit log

2025-08-25 ancp test staton hw v1.0
    [Battery.kicad_sch, Load Cell, ADC.kicad_sch, MCU.kicad_sch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]
2025-08-25 hw v2.0 update
    [ADC&Ref.kicad_sch, Battery.kicad_sch, Load Cell, ADC.kicad_sch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]
2025-08-25 ancp motor test station fw v1.0 update

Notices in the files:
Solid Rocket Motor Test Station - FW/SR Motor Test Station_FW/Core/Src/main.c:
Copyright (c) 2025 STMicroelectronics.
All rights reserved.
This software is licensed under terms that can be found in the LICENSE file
